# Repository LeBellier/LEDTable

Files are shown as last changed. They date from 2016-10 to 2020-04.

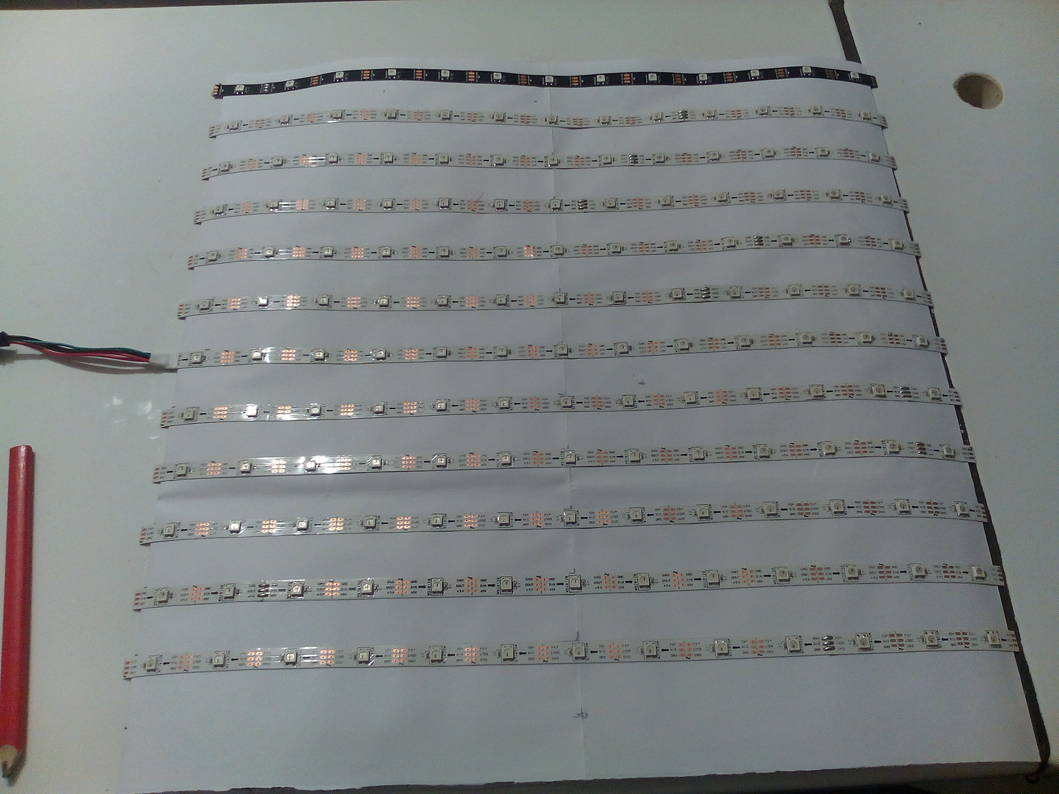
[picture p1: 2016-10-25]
Photos/2016-09-18 17.08.49.jpg

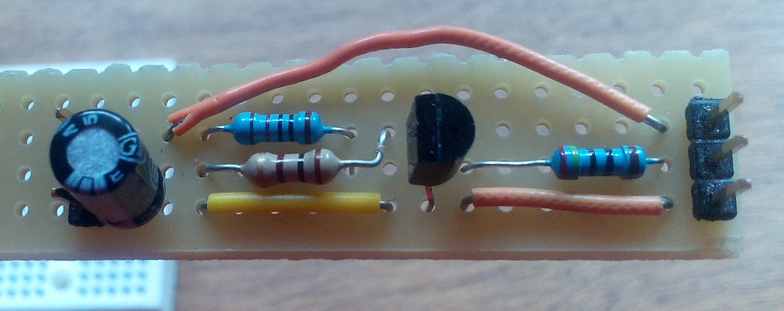
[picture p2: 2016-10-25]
Photos/2016-09-05 17.18.38.jpg

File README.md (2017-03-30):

# Table à LED
J'ai vu un collègue en faire une, alors je me suis dit pour quoi pas moi.
## En résumé :
- J'ai utilisé des leds **NeoPixel** (ws2812b)
- Commandées par une **carte électronique**
- Commandée par un **ESP-12E** (MCU Node v1.0)
- Commandé par :
	- Une interface web
	- Une application PC, qui envoie des trames DMX en Wifi

## Libraires utilisées
-https://github.com/LeBellier/GeneralLibEsp8266
- https://github.com/rstephan/ArtnetWifi 

## Contributing
- Fork it
- Create your feature branch (git checkout -b my-new-feature)
- Commit your changes (git commit -am 'Add some feature')
- Push to the branch (git push origin my-new-feature)
- Create new Pull Request

> Written with [StackEdit](https://stackedit.io/).

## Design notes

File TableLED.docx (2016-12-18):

# Table à LED

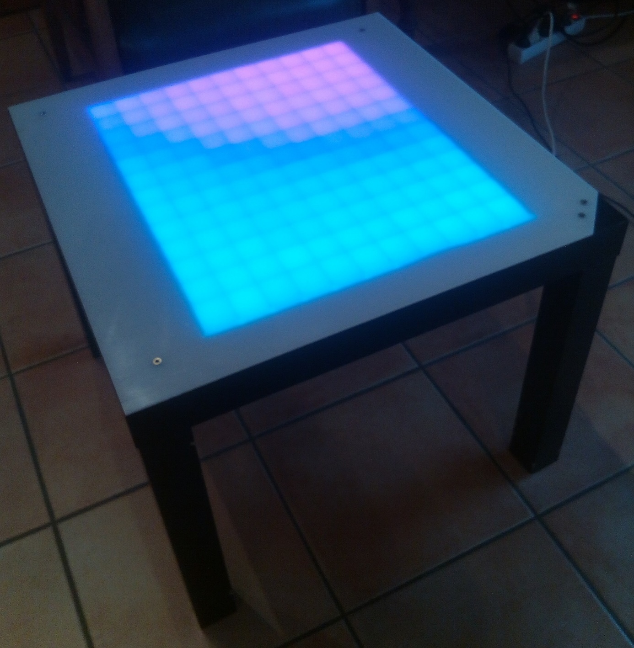
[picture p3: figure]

# 1. Description

À l'image du projet d'ici (http://127.cap-sciences.net/) j'ai fait une table à LED en partant d'une base de table IKEA.

https://github.com/LeBellier/LEDTable

Matériel :

- 1 table IKEA (50cm*50cm)
- 1 ruban de LED WS2812 suffisamment grand (30LED/m, 5.2m pour faire une matrice 13*12 LED)
- 1 bobine de petit fils
- 1 feuille de 50cm*50cm
- 1 plaque de Plexiglass de 50cm*50cm
- 1 plaque de carton ondulé 1mm
- 1 Alimentation 5V,10A
- Des composants électroniques :
  - R1 10 kohm
  - R2 240 ohm
  - R3 100 ohm
  - C1 100 uF, 16 V

# 2. Principe Général de fonctionnement

Utilisateur
ESP8266
CarteElectronique
LED
Via un seveur web
Via des Trames ArtNet

J’ai développé deux moyens d’interagir avec la table.

Le premier est un serveur web, avec une page web qui s’affiche. Tout est dans la table.

Le second, est l’envoie de trame ArtNet via une application que vous aurez créée.

Pourquoi un ESP8266, parce qu’il est petit, et intègre sur sa carte le WIFI. Le problème est qu’il fonctionne avec des entrée/sorties à 3.3V, c’est pourquoi il y l’étape de la carte électronique, avec un simple transistor. Cela permet de transformer le 3V3 en 5V. Les LED peuvent donc être commandées par le signal de sortie de la carte.

Enfin, les LEDs sont en ruban. J’ai acheté un ruban de WS2812B, avec 30led/m. Ces leds reçoivent un signal série avec l’adresse de la led, niveau de rouge, niveaux de vert, niveau de bleu.

# 3. Recette de réalisation du projet

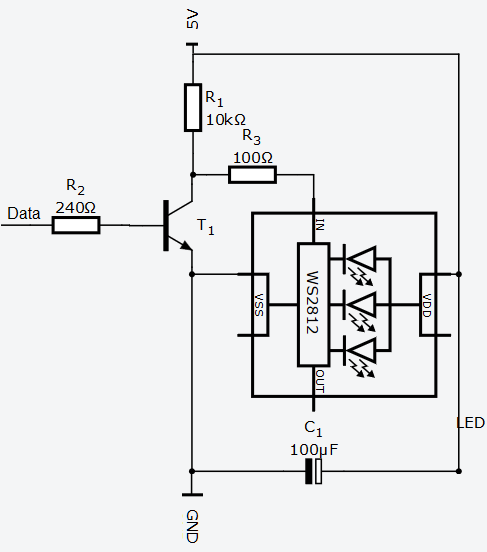
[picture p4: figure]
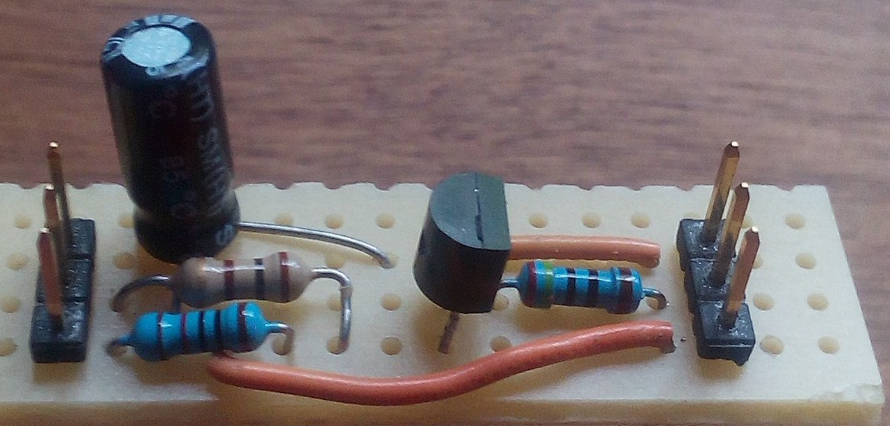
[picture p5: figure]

## Conception électronique

La première étape est de faire la carte électronique. Il y a plusieurs manières pour réaliser la carte. Soit vous faites comme moi avec une plaque de prototype époxy perforée, soit réalisez un circuit imprimé. Le circuit ci-contre représente les liens entre les composants. 3 fils relient l’esp à la carte : 5V, Data et GND. 3 fils relient la carte à la première led : 5V, In et GND. Assembler les composants de la liste de matériel en vous aidant du schéma ci-dessous, de l'image et du lien : https://circuits.io/circuits/2307914-esp-strip-ws2812b/
La résistance R2, sera connecté au micro-contrôler et la R3, sera connectée à l'entrée de la première LED. Pour les connecteurs, j’ai choisi des header pins mais ca c’est mon choix.

Grâce à cette carte vous pourrez tester et jouer avec un ruban de led. Pour plus d’image allez à « /Photos ». Il y a un programme de test dans « /CodeArduino/TestStrip ».

## Découpe de la table

Pour cette étape je suis désolé mais je n’ai pas prise de photos… Il faut faire un trou dans la table de la taille que vous voulez, j’ai fait un trou de 45cm*45cm. Ensuite il faut vider la table : enlever les toutes alvéoles.

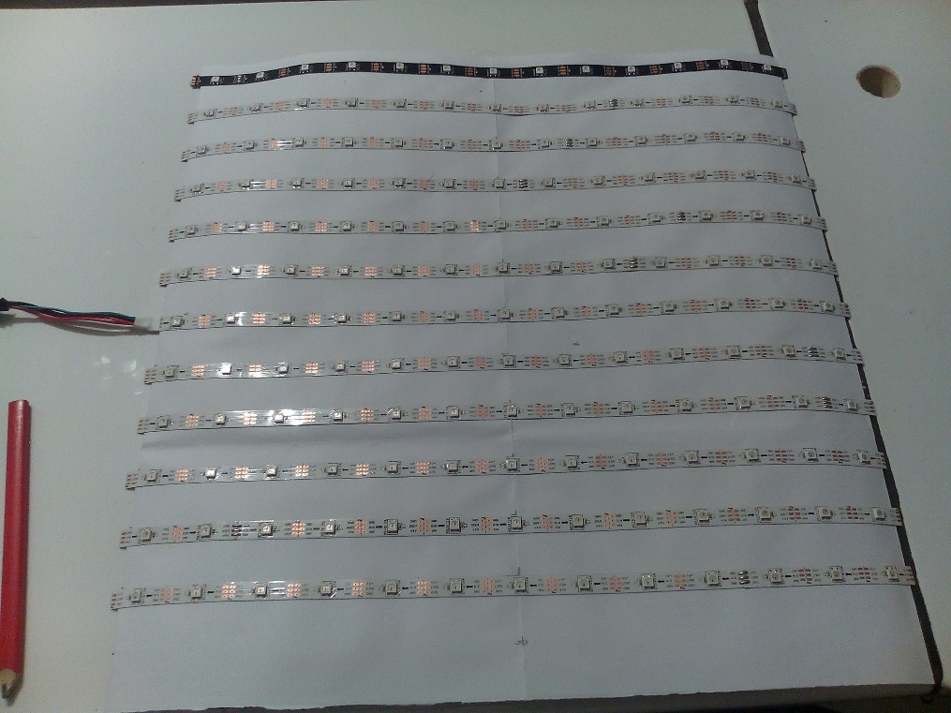
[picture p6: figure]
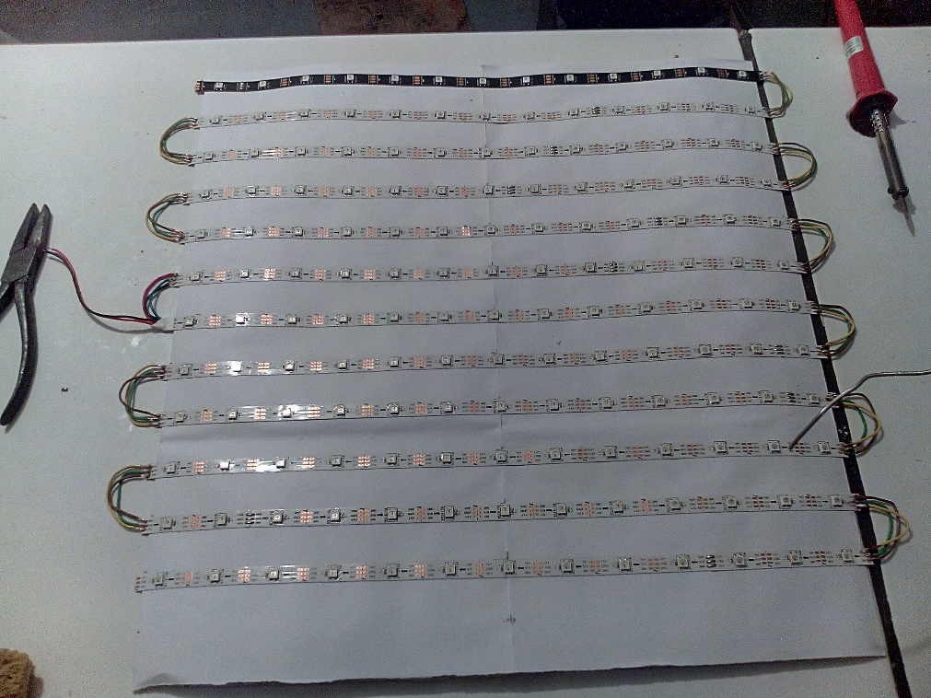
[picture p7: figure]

## Découpe du ruban

Pour la découpe du ruban, il faut bien suivre la ligne sur le ruban. Pour ma part j’ai découpé 12 bandes de 13 LEDs. Pour former ma matrice j’ai utilisé une feuille carrée car il faut placer les bandes dans le BON sens. En effet, la sortie d’une LED ne peut être connectée qu’à l’entrée de la suivante. Une fois mise en place, il faut coller les bandes avec un entraxe de 33mm (si vous avez des 30LED/m). Dernière étape il faut souder les 5V, GND et DATA pour chaque bande.

Vous remarquerez peut-être que j’ai 2 fils au milieu qui dépasse. Oui c’est en effet fait exprès. Le 5V étant une basse tension, il risque de ne pas rester constant si le fils mesure 5m, donc si le point d’entrée est au milieu, ça fait 2.5m de chaque côté :p

Chaque LED peut consommer 3*20mA. J’ai 13*12 LED, ce qui fait 9,360A. Tout ce courant ne pourra etre obtenu qu’avec un AC/DC (Secteur/5v) spécifique.

NB : ne pas faire comme moi, et prendre des rubans différent (la bande noir, des bandes blanche), car la différence se voit à la fin.

## Découpe et Assemblage du carton

Pour les cloisons je vous conseil du carton ondulé fin. Vous trouverez les fichiers Illustrator dans le dossier Modélisation du git

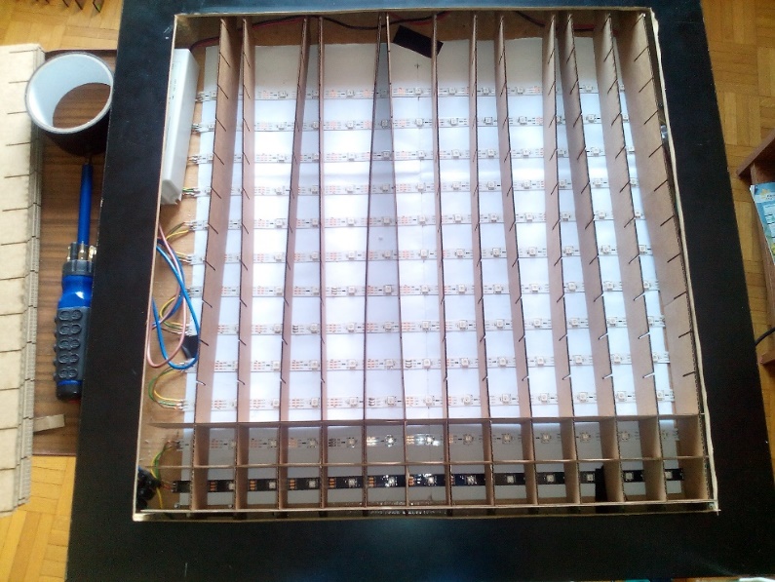
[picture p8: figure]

## Découpe et fixation plexi

Pour la découpe, j’ai découpé un carré, et je l’ai fixé dans les angles, là où la table est pleine.

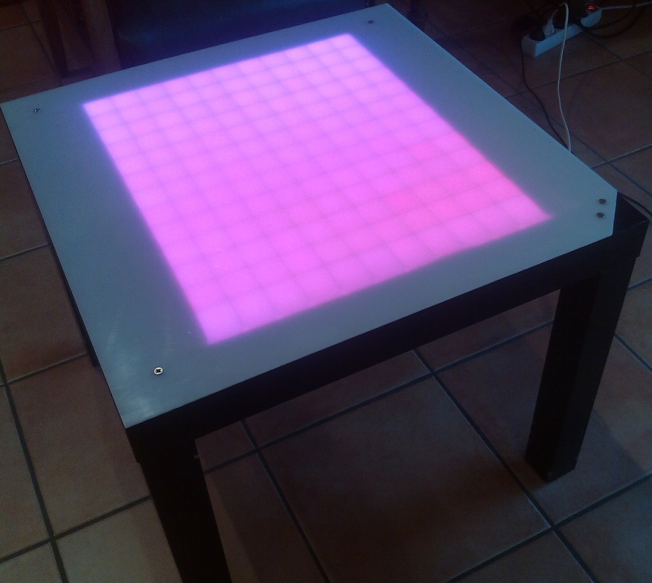
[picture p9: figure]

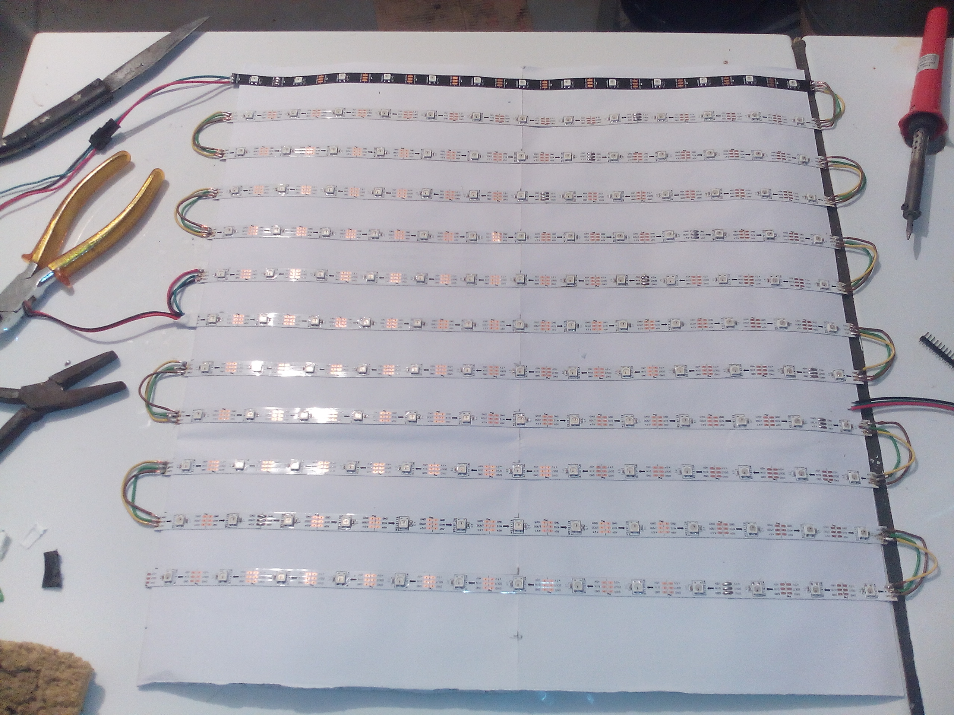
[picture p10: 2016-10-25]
Photos/2016-09-18 19.37.47.jpg

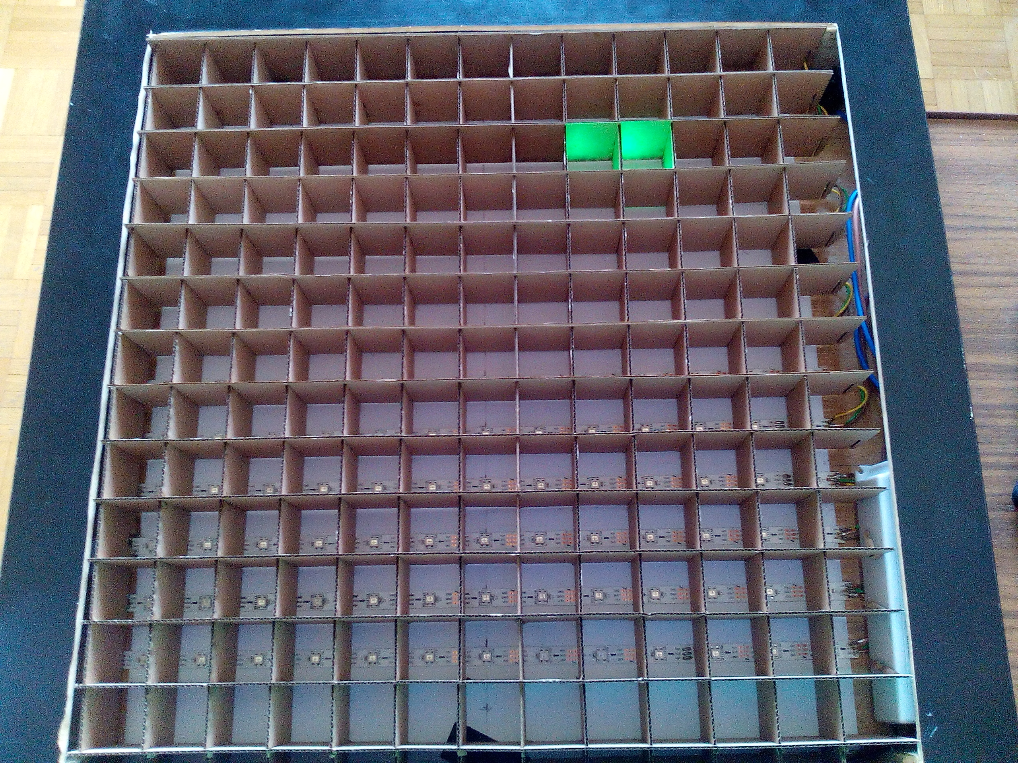
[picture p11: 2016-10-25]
Photos/2016-09-26 12.21.25.jpg

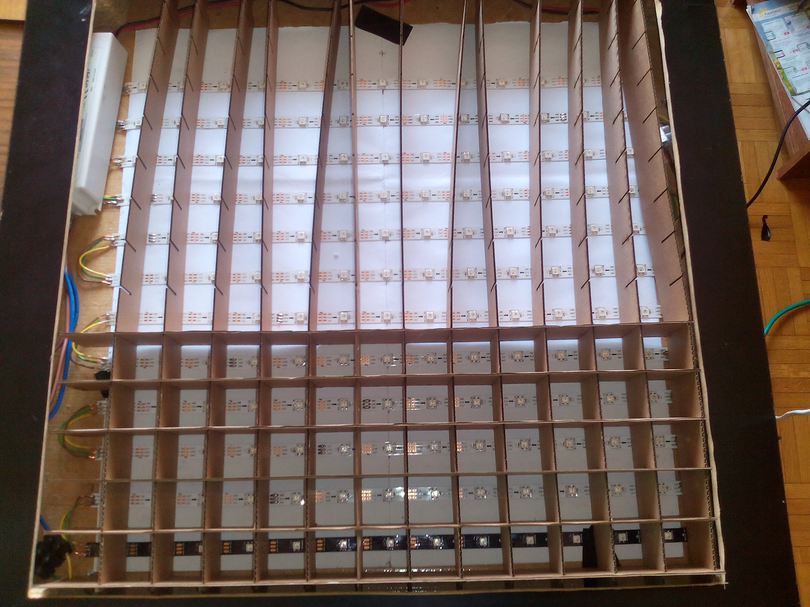
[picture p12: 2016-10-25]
Photos/2016-09-26 12.01.50.jpg

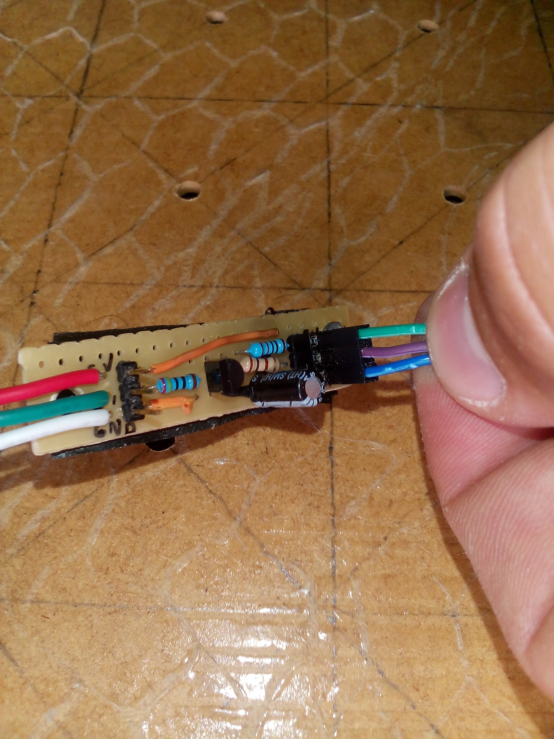
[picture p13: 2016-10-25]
Photos/2016-09-26 10.01.26.jpg

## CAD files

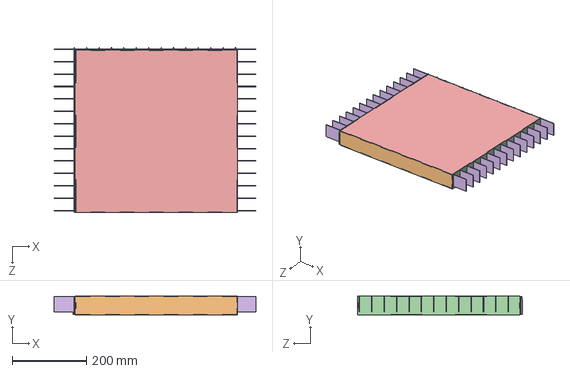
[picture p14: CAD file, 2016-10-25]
Modélisation/Assemblage.SLDASM
543.0 x 51.0 x 443.5 mm
cloison x 28

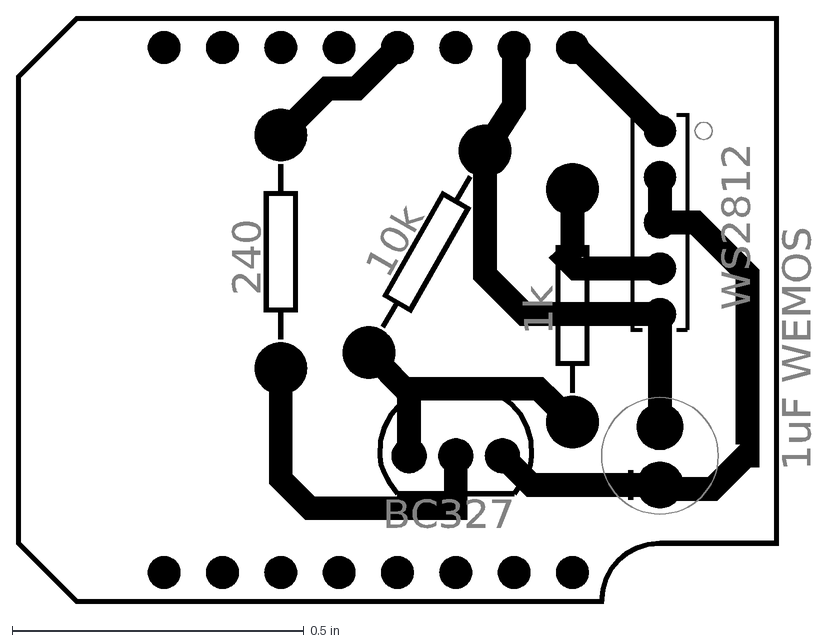
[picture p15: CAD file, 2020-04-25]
Electronique/Modeling/Interface.DXF
BC327
240
10k
1k
WEMOS
1uF
WS2812

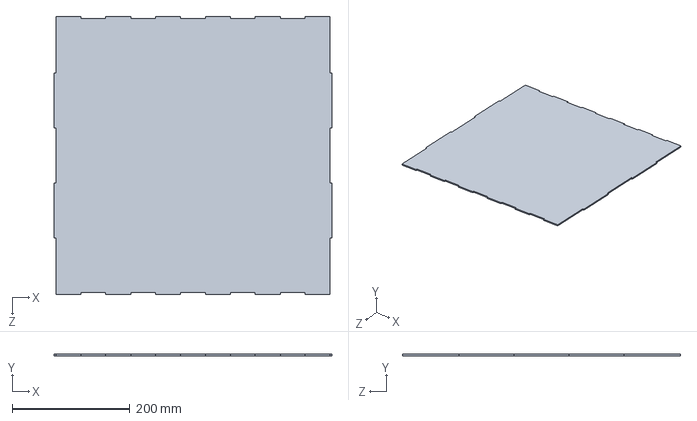
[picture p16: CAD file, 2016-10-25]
Modélisation/Top.SLDPRT
473.0 x 3.00 x 473.0 mm

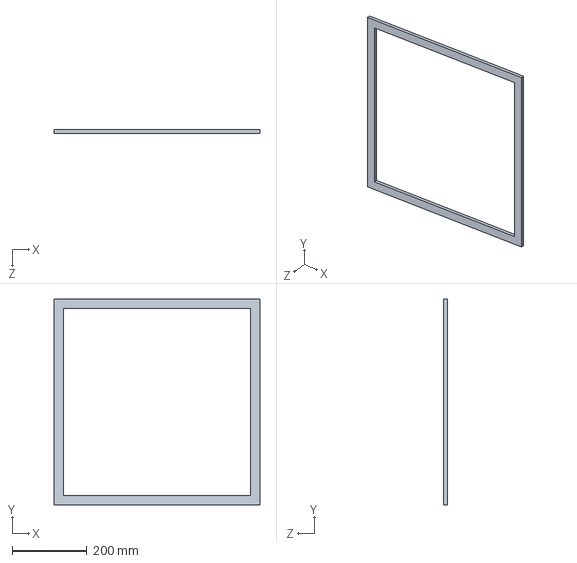
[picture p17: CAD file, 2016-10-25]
Modélisation/PlaqueDessus.SLDPRT
550.0 x 550.0 x 10.0 mm

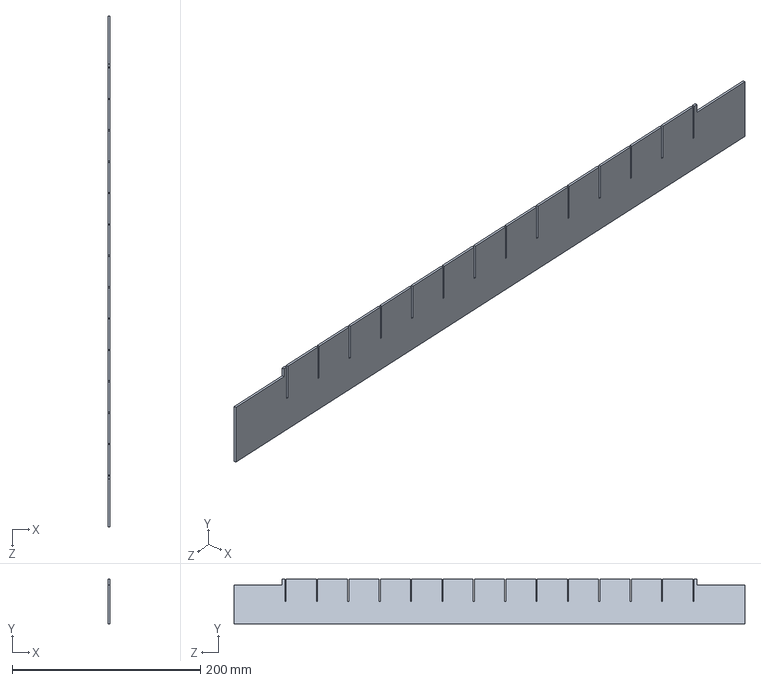
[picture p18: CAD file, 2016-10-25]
Modélisation/cloison.SLDPRT
1.60 x 47.5 x 543.0 mm

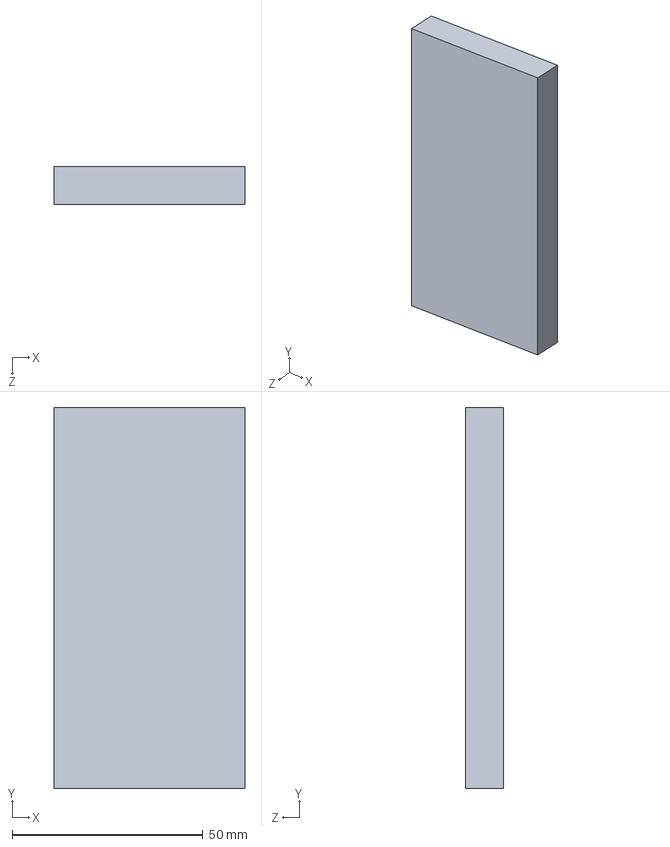
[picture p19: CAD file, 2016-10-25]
Modélisation/Etalon 100x50.SLDPRT
50.0 x 100.0 x 10.0 mm

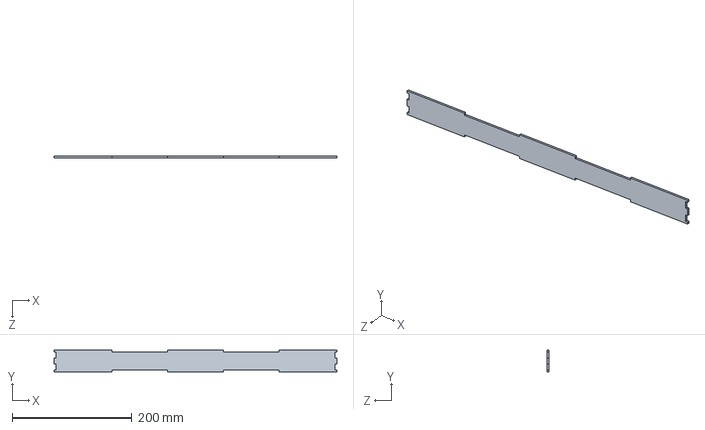
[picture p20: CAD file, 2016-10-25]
Modélisation/Back.SLDPRT
473.0 x 36.3 x 3.00 mm

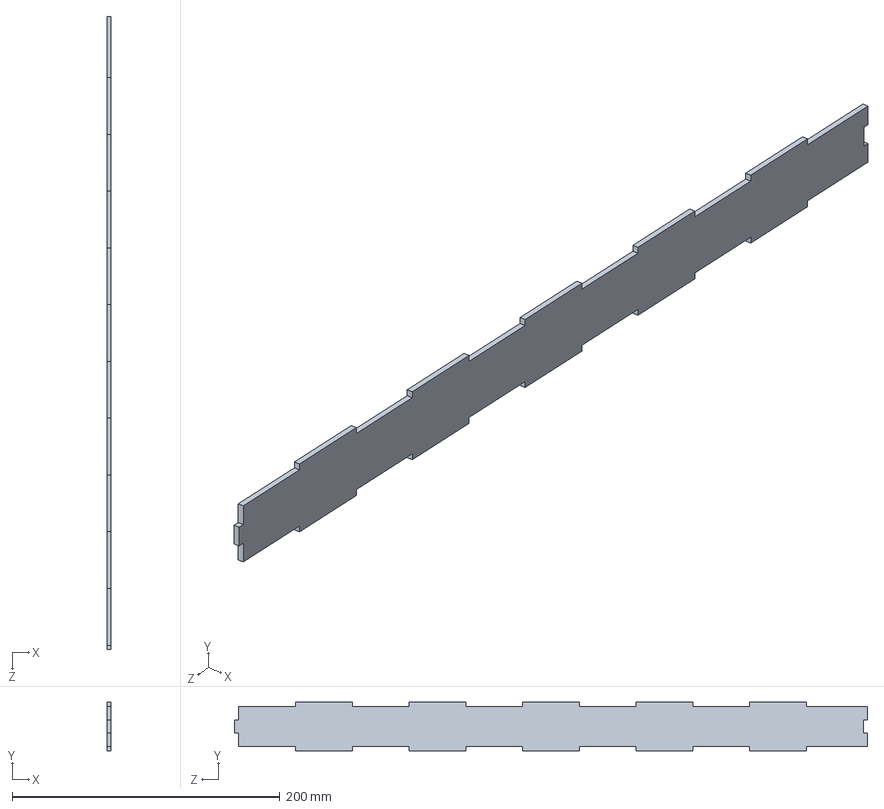
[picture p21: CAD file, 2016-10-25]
Modélisation/Edge.SLDPRT
3.00 x 36.3 x 473.0 mm

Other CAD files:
Modélisation/Bottom.SLDPRT
Modélisation/Front.SLDPRT
Modélisation/PlaqueDessus.SLDDRW
Modélisation/cloison.SLDDRW

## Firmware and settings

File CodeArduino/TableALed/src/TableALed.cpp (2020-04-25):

#include "TAL.h"

void setup(void)
{
	Serial.begin(BAUDRATE);
	Serial.println("");
	Serial.println("Nouvelle version 3");
	pinMode(led, OUTPUT);
	digitalWrite(led, 0);
	MatrixStrip.init(pixelPin, nbRows, nbColumns);
	MatrixStrip.rgbBlink();

	WiFiManager wifiManager;
	//reset settings - for testing
	// wifiManager.resetSettings();

	//set callback that gets called when connecting to previous WiFi fails, and enters Access Point mode
	//wifiManager.setAPCallback(configModeCallback);

	//fetches ssid and pass and tries to connect
	//if it does not connect it starts an access point with the specified name
	//here  "AutoConnectAP"
	//and goes into a blocking loop awaiting configuration
	if (!wifiManager.autoConnect())
	{
		Serial.println("failed to connect and hit timeout");
		//reset and try again, or maybe put it to deep sleep
		ESP.reset();
		delay(1000);
	}

#ifdef DEBUG_INIT
	delay(15);
#endif
	artnet.setArtDmxCallback(onDmxFrame);
	artnet.begin();
	svrs.setServersON(B11111);

#ifdef DEBUG_INIT
	delay(20);
#endif
	svrs.httpSvr->onNotFound(handleRequestOnFile);
	svrs.httpSvr->on("/pixel", HTTP_GET, pixelRequest);
	svrs.setReadTelnetCallback(parseTelnet);

	if (WiFi.getMode() != WIFI_STA)
	{
		showIP(WiFi.softAPIP());
	}
	else
	{
		showIP(WiFi.localIP());
	}
	digitalWrite(led, 1);
}

void loop()
{
	svrs.update();
	artnet.read();
	startShow(anim);
}

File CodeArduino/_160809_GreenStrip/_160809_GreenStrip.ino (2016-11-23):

/*
 * Standard strip test:
 *  switch in green one by one each NeoPixel.
 */

#include <Adafruit_NeoPixel.h>
#ifdef __AVR__
#include <avr/power.h>
#endif

// Which pin on the Arduino is connected to the NeoPixels?
// On a Trinket or Gemma we suggest changing this to 1
#define PIN            D3

// How many NeoPixels are attached to the Arduino?
#define NUMPIXELS      156

// When we setup the NeoPixel library, we tell it how many pixels, and which pin to use to send signals.
// Note that for older NeoPixel strips you might need to change the third parameter--see the strandtest
// example for more information on possible values.
Adafruit_NeoPixel pixels = Adafruit_NeoPixel(NUMPIXELS, PIN, NEO_GRB + NEO_KHZ800);

int delayval = 50;

void setup() {
  // This is for Trinket 5V 16MHz, you can remove these three lines if you are not using a Trinket
#if defined (__AVR_ATtiny85__)
  if (F_CPU == 16000000) clock_prescale_set(clock_div_1);
#endif
  // End of trinket special code

  pixels.begin(); // This initializes the NeoPixel library.
}

void loop() {

  // For a set of NeoPixels the first NeoPixel is 0, second is 1, 
  //all the way up to the count of pixels minus one.
  for (int i = 0; i < NUMPIXELS; i++) {

    // pixels.Color takes RGB values, from 0,0,0 up to 255,255,255
    pixels.setPixelColor(i, pixels.Color(0, 150, 0)); // Moderately bright green color.
    pixels.show(); // This sends the updated pixel color to the hardware.

    delay(delayval); // Delay for a period of time (in milliseconds).
    pixels.setPixelColor(i, pixels.Color(0, 0, 0)); // Moderately bright green color.
  }
}

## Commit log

2016-09-15 Relaese, working: -TODO: Tidy clas's responsability -TODO: The ESP undstand only the first DMX frame... -TODO: Add Hardware projet
2016-09-19 Relaese, working: -TODO: The ESP undstand only the first DMX frame... -TODO: Add Hardware projet
2016-11-23 Sort files
    [Chiffres.xlsx]
2016-12-18 test .gitignore
    Succes : il faut ignorer seulement des nouveau fichier !
2016-12-18 Reorganisation suite à une formation sur les principes de Git et GitHub, je range mon projet :factory:
2016-12-18 Fin Reorganisation: suppression des fichiers personnels
2016-12-22 Ajout de l'animation en spirale
    [Chiffres.xlsx]
2016-12-22 Correction spirale
    Il y avait une erreur dans la char* spirale
    Ustilisation de la spirale
2016-12-22 Reorganisation suite a une formation sur les principes de Git et GitHub, je range mon projet :factory:. Suppression des fichiers personnels
2017-01-18 Fin des tests debug
    Changement pour une méthodes moins lourde à utiliser.
2017-01-18 debut de mutualisation
2017-01-18 Mutualisation faite
    En attente de tests
2017-01-20 Add Datasheet for LED
2017-01-20 Intégration Acces point si pas de wifi connu
2017-01-23 Edit formatter
    The same on eclipse and arduino IDE
2017-02-15 Migrate from Arduino IDE to Sloeber
    Sloeber is an Eclipse plugin for arduino.
2017-02-15 CLean up the code
    And Create an excel to dont forget task
    [Gestion projet.xlsx]
2017-02-15 Start to delete GlobaleVars
    [Gestion projet.xlsx]
2017-03-08 Echec de la vie
2017-03-08 Revert "Echec de la vie"
    This reverts commit b26d3e7487fd00c989e28ffacd0de08b6baf6da9.
    [ESPTable.ino]
2017-03-09 Telnet print debug
2017-03-12 simplification des user and passeword
2017-09-02 Production circuit
    [Interface.DXF]
2017-09-02 Sample captive portal
2017-09-05 Finition
    intégration de la nouvelle lib
2017-09-12 Version Fonctionnelle
    Telnet server repondant que a "q"
2018-02-24 Incorporation de la librairie "Generale" pour éviter les probleme de complie et en plus ca sert à rien d'avoir une lib
    [GlobalVars.h]
2018-02-25 Changement nom dossier
    [Gestion projet.xlsx]
2018-02-25 Re changement de nom pour igorné les fichiers de compilation
2018-03-13 Renommage variable ! Tout fonctionne j'arrete la.
2020-04-25 [ESP Code] PlatformIO Migration OKAY
    [Interface.DXF]
